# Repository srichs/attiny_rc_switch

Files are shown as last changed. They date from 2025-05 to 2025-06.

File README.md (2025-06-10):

# ATtiny RC Switch

On/Off Switch for RC models driven by PWM signal. Based on ATtiny85, 12V capable. Original project is located [here](https://github.com/DzikuVx/attiny_rc_switch).

This small device allows to turn on/off different devices on RC devices: airplanes, quadcopter drones, cars. 
It uses one RC PWM channel as input and provides power on output pins when channel pulse length is above 1700us.
Excellent to switch LED strips. Output current is up to 500mA.

AVR ATtiny x5 series microcontroller. Compiled code takes slightly above 2kB, so will fit into ATtiny45 and ATtiny85. When smoothing is removed, code will fit into ATtiny25.

To program you can use the [AVR Pocket Programmer](https://www.digikey.com/en/products/detail/sparkfun-electronics/09825/5230949), which costs $20. It is easiest to use a clip to program the microcontroller such as [these](https://www.amazon.com/EC-Buying-Detachable-Programmer-Testing/dp/B0C73GXRR2) or [these](https://www.amazon.com/Programmer-Testing-SOP16-SOIC8-SOIC16/dp/B0CBNG59CB).

## ATtiny RC Switch SMD

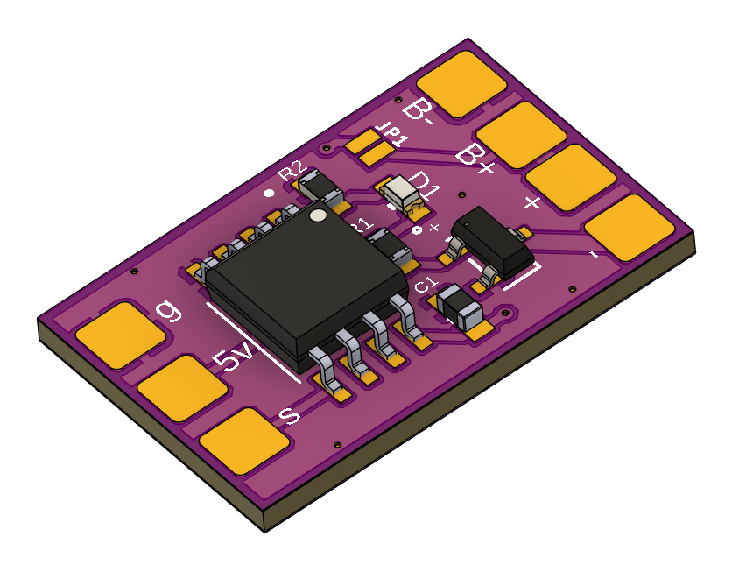
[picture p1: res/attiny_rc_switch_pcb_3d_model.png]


Order the PCB [here](https://oshpark.com/shared_projects/qRILFycT)

## Hardware

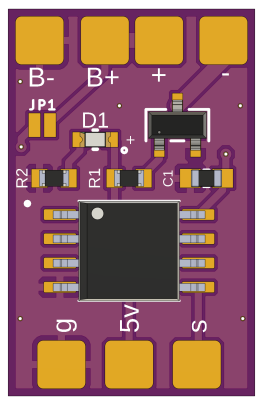
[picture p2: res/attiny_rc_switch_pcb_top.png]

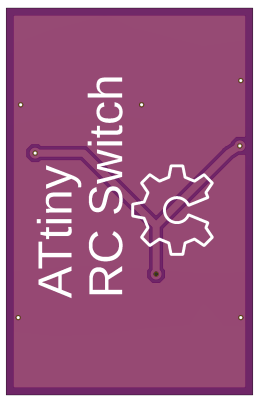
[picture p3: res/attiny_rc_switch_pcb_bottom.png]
PCB Bottom


### BOM

| Label |Part No | Name | Quantity | Subtotal | Link |
|---|---|---|---|---|---|
| U1 | ATTINY85-20SU | ATtiny85 Microcontroller | 1 | $1.50 | [DigiKey](https://www.digikey.com/en/products/detail/microchip-technology/ATTINY85-20SU/735470) |
| U2 | IRLML2502TRPBF | N-Channel MOSFET, 20V, 4.2A SOT-23 | 1 | $0.43 | [DigiKey](https://www.digikey.com/en/products/detail/infineon-technologies/IRLML2502TRPBF/812502) |
| D1 | LTST-C190KRKT | Red LED, SMD 0603, Clear | 1 | $0.14 | [DigiKey](https://www.digikey.com/en/products/detail/liteon/LTST-C190KRKT/386817) |
| R1,R2 | CRGCQ0603F470R | 470 Ohm Resistor, SMD 0603, 1/10W | 2 | $0.20 | [DigiKey](https://www.digikey.com/en/products/detail/te-connectivity-passive-product/CRGCQ0603F470R/8576286) |
| C1 | CC0603KRX7R7BB104 | 0.1uF Capacitor, SMD 0603, 16V | 1 | $0.08 | [DigiKey](https://www.digikey.com/en/products/detail/yageo/CC0603KRX7R7BB104/302822) |
|  | qRILFycT | PCB | 1 | $0.68 | [OSH Park](https://oshpark.com/shared_projects/qRILFycT) |
|  |  |  | Total | $3.03 |  |

### Schematic

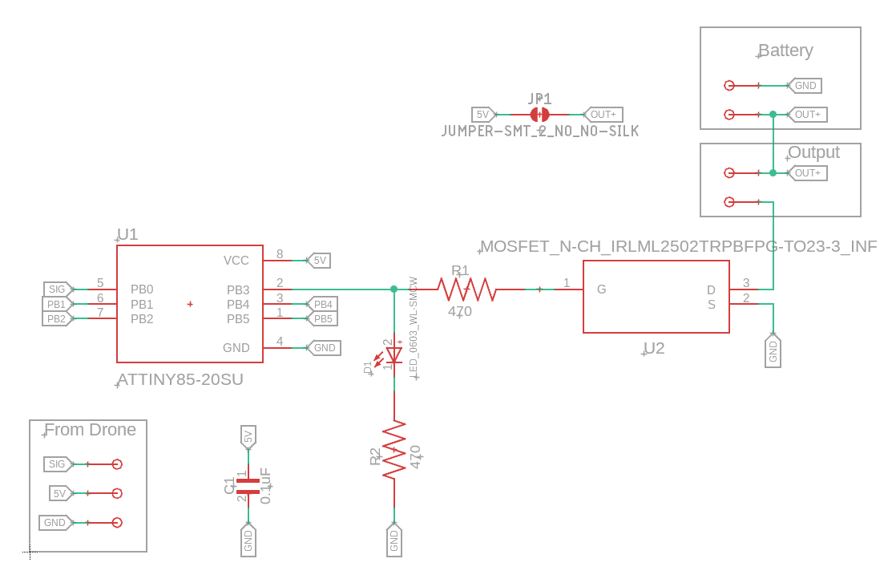
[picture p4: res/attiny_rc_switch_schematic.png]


## ATtiny RC Switch Through Hole

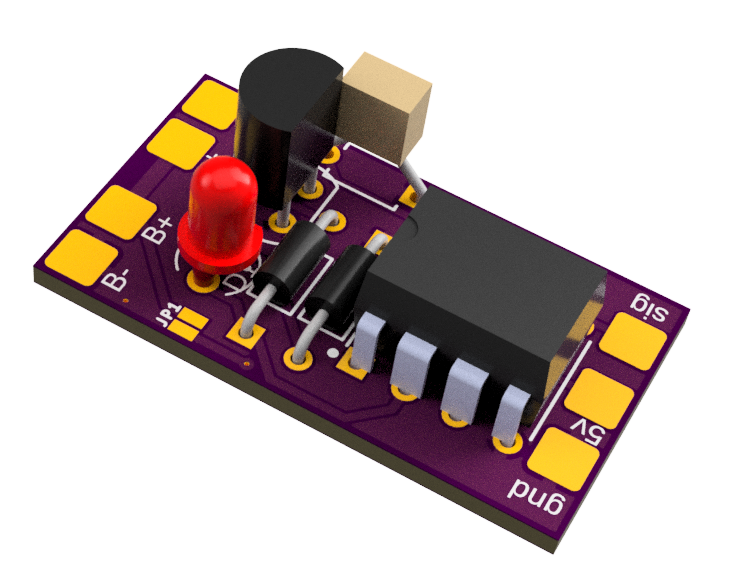
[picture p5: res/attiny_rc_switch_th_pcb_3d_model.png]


Order the PCB [here](https://oshpark.com/)

## Hardware

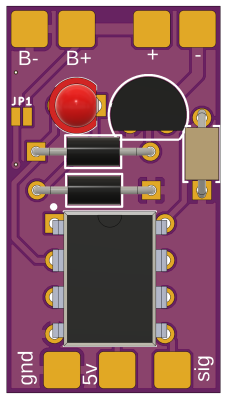
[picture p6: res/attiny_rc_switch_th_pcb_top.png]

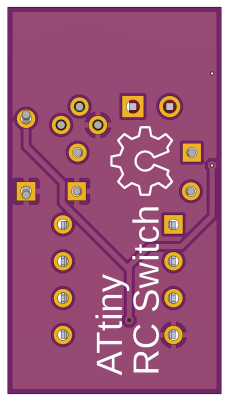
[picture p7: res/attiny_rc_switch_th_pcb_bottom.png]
PCB Bottom


### BOM

| Label |Part No | Name | Quantity | Subtotal | Link |
|---|---|---|---|---|---|
| U1 | ATTINY85-20PU | ATtiny85 Microcontroller | 1 | $1.66 | [DigiKey](https://www.digikey.com/en/products/detail/microchip-technology/ATTINY85-20PU/735469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) |
| U2 | SS8050DTA | NPN BJT, 25V, 1.5A TO92-3 | 1 | $0.37 | [DigiKey](https://www.digikey.com/en/products/detail/onsemi/SS8050DTA/1047325) |
| D1 | 151033RS03000 | Red LED, Round, 3mm, Clear | 1 | $0.16 | [DigiKey](https://www.digikey.com/en/products/detail/w%C3%BCrth-elektronik/151033RS03000/4490003) |
| R1,R2 | CF18JT470R | 470 Ohm Resistor, 1/8W, Axial | 2 | $0.20 | [DigiKey](https://www.digikey.com/en/products/detail/stackpole-electronics-inc/CF18JT470R/1741717) |
| C1 | A104K15X7RF5TAA | 0.1uF Capacitor, 50V, Axial | 1 | $0.26 | [DigiKey](https://www.digikey.com/en/products/detail/vishay-beyschlag-draloric-bc-components/A104K15X7RF5TAA/146011) |
|  |  |  | Total | $2.65 |  |

### Schematic

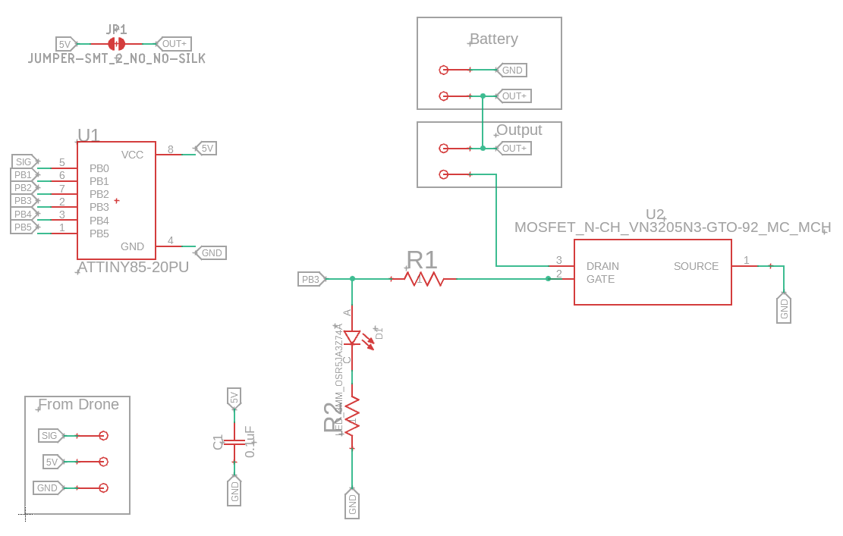
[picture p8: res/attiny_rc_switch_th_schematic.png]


## Notes

* Arduino IDE 1.6.6. Should work on older releases, but never tested

* ATtiny45/85 board definitions. Tested with [damellis/attiny](https://github.com/damellis/attiny)

* Uses 1MHz internal osciallator

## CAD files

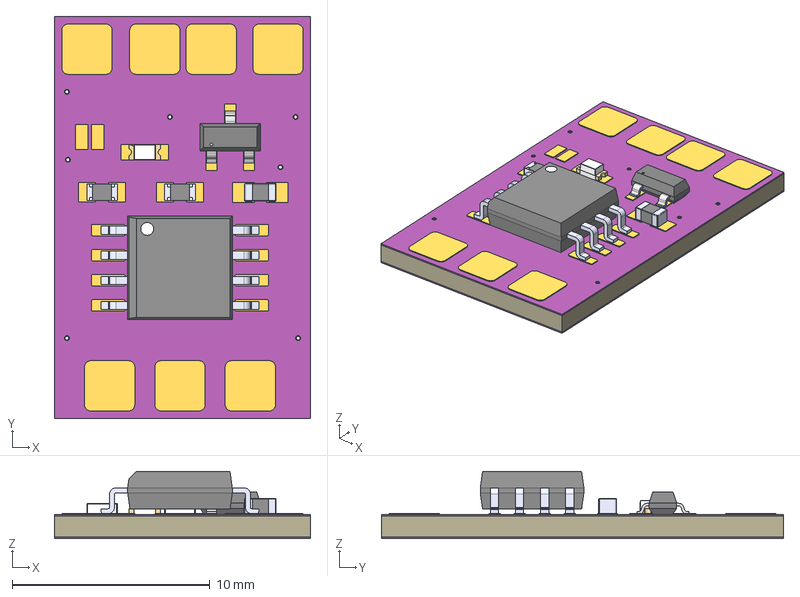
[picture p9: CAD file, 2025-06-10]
pcb/attiny_rc_switch_3d_model.step
13.0 x 20.3 x 3.39 mm
Board
1-copper
16-copper
1-soldermask
16-soldermask
ATTINY85-20SU v1
CC0603ZRY5V9BB104 v1
RCS060310K0JNEA v1 x 2
housing
cover
base x 2
Polarity Mark
IRLML2502TRPBF v1

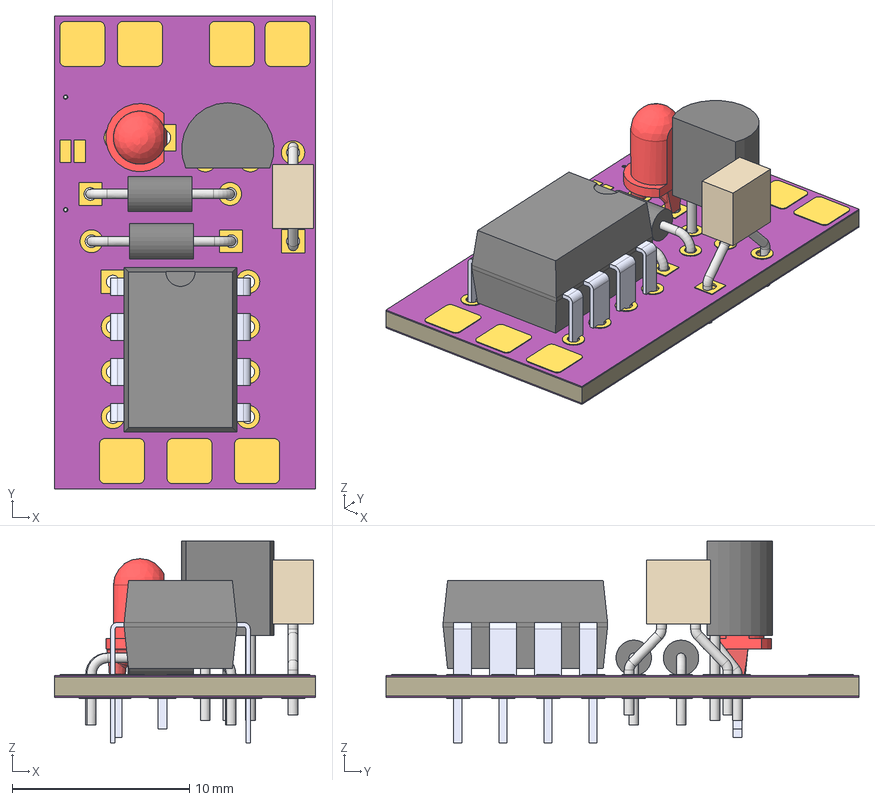
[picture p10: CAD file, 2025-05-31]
pcb/attiny_rc_switch_th_3d_model.step
14.7 x 26.7 x 11.4 mm
Board
ATTINY85-20PU v1
K103K10X7RF5UH5 v1
VN3205N3_G v1
RES_1-8W v1 x 2
OSR5JA3Z74A_OSR5JA3Z74A
SMD_PAD_NO_STENCIL x 7
1-copper
16-copper
1-soldermask
16-soldermask

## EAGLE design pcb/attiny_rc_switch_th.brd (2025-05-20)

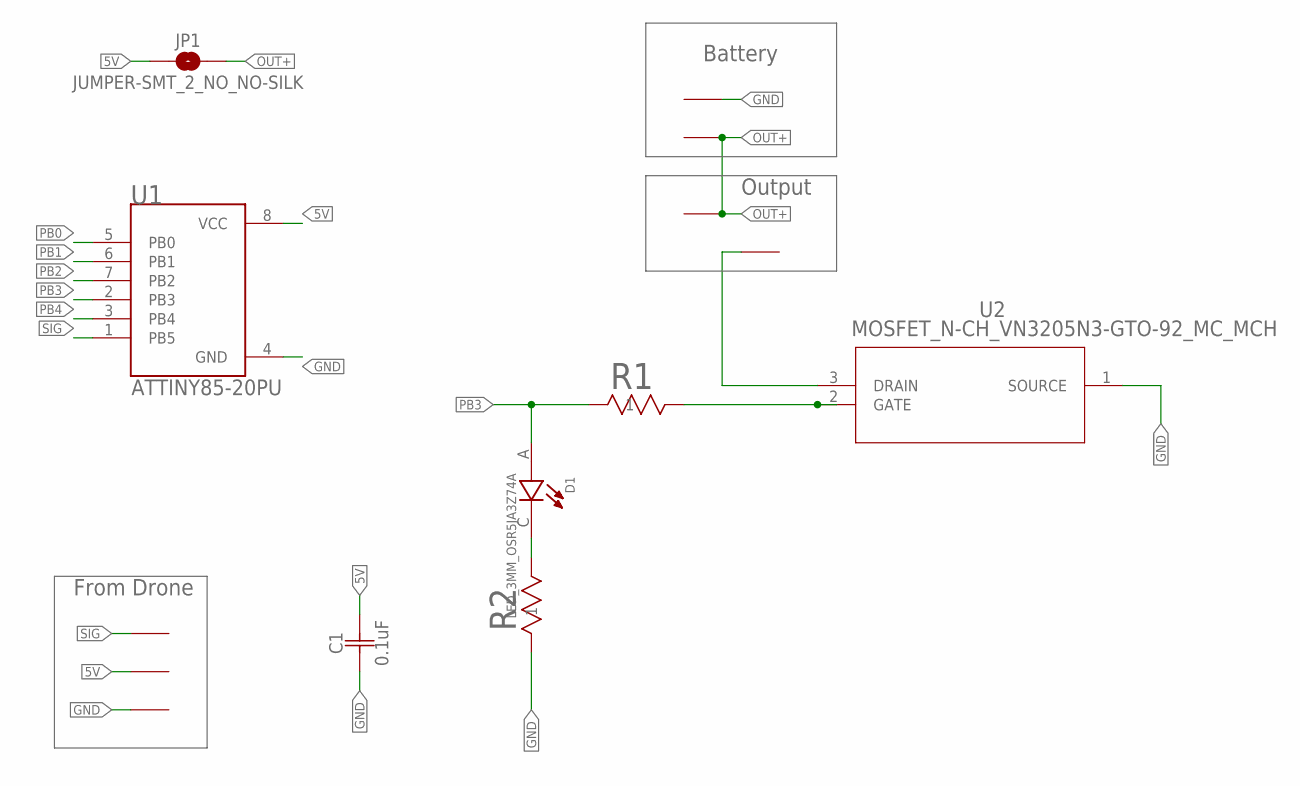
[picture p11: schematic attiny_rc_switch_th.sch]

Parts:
C1: 0.1uF; K10XK10X7RF5UH5
D1: LED_3MM_OSR5JA3Z74A; OSR5JA3Z74A
JP1: JUMPER-SMT_2_NO_NO-SILK; SMT-JUMPER_2_NO_NO-SILK
R1, R2: RESISTOR_1/8W_CF18JTSTA_CF18_STP; RESISTOR_1/8W_CF18JT
U1: ATTINY85-20PU
U2: MOSFET_N-CH_VN3205N3-GTO-92_MC_MCH; MOSFET_N-CH_VN3205N3-G
U$1, U$2, U$3, U$4, U$5, U$6, U$8: SMD_PAD

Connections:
5V: C1.2, JP1.1, U1.8 (VCC), U$1.P$1
GND: C1.1, R2.1, U1.4 (GND), U2.1 (SOURCE), U$2.P$1, U$4.P$1
unnamed: R1.2, U2.2 (GATE)
unnamed: D1.C, R2.2
OUT+: JP1.2, U$3.P$1, U$5.P$1
OUT-: U2.3 (DRAIN), U$6.P$1
PB0: U1.5 (PB0)
PB1: U1.6 (PB1)
PB2: U1.7 (PB2)
PB3: D1.A, R1.1, U1.2 (PB3)
PB4: U1.3 (PB4)
SIG: U1.1 (PB5), U$8.P$1

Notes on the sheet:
From Drone
Battery
Output

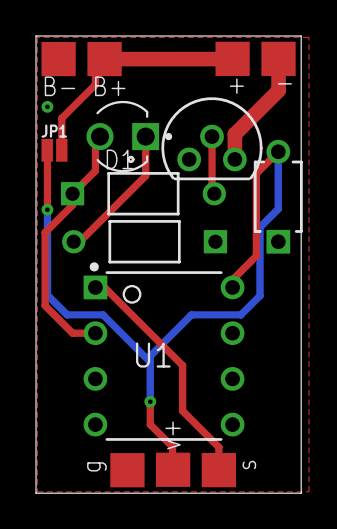
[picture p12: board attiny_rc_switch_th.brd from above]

Board: 2 copper layers, 14.7 x 25.4 mm, 14 parts (0 on the bottom side), 8 nets.

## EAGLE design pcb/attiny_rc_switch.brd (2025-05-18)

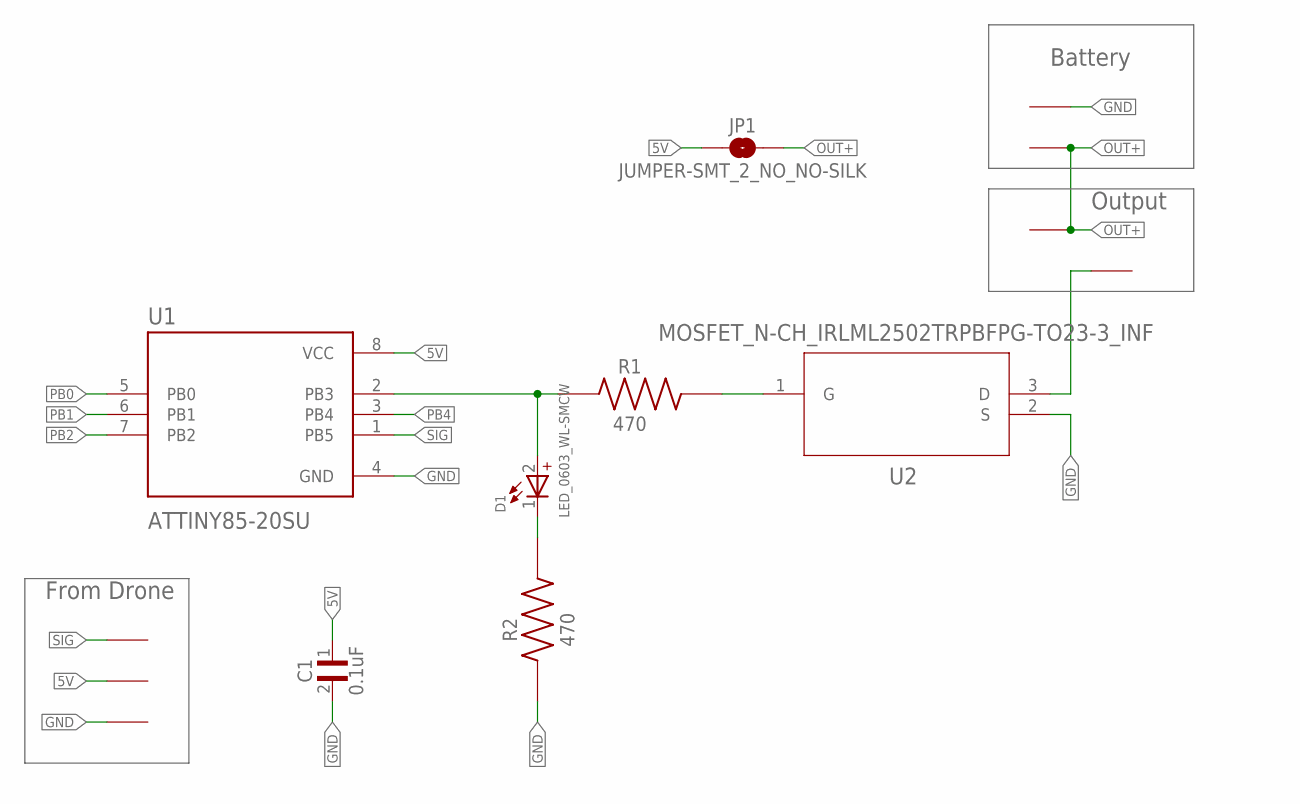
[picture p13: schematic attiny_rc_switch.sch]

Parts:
C1: 0.1uF; CC0603ZRY5V9BB
D1: LED_0603_WL-SMCW
JP1: JUMPER-SMT_2_NO_NO-SILK; SMT-JUMPER_2_NO_NO-SILK
R1, R2: 470; RCS0603
U1: ATTINY85-20SU
U2: MOSFET_N-CH_IRLML2502TRPBFPG-TO23-3_INF; MOSFET_N-CH_IRLML2502TRPBF
U$1, U$2, U$3, U$4, U$5, U$6, U$8: SMD_PAD

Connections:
5V: C1.1, JP1.1, U1.8 (VCC), U$1.P$1
GND: C1.2, R2.1, U1.4 (GND), U2.2 (S), U$2.P$1, U$4.P$1
unnamed: D1.2 (+), R1.1, U1.2 (PB3)
unnamed: R1.2, U2.1 (G)
unnamed: D1.1 (-), R2.2
OUT+: JP1.2, U$3.P$1, U$5.P$1
OUT-: U2.3 (D), U$6.P$1
PB0: U1.5 (PB0)
PB1: U1.6 (PB1)
PB2: U1.7 (PB2)
PB4: U1.3 (PB4)
SIG: U1.1 (PB5), U$8.P$1

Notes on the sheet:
From Drone
Battery
Output

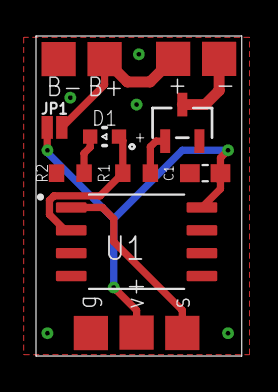
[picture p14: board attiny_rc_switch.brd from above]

Board: 2 copper layers, 11.4 x 17.8 mm, 14 parts (0 on the bottom side), 8 nets.

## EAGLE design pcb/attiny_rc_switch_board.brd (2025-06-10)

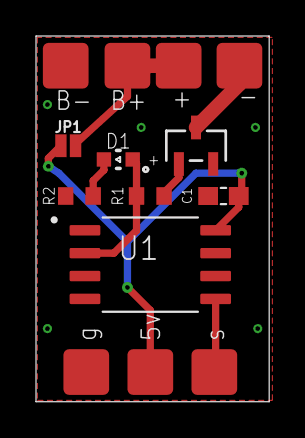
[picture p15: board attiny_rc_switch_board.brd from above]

Board: 2 copper layers, 13.0 x 20.3 mm, 14 parts (0 on the bottom side), 8 nets.

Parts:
C1: 0.1uF; CC0603ZRY5V9BB
D1: LED_0603_WL-SMCW
JP1: JUMPER-SMT_2_NO_NO-SILK; SMT-JUMPER_2_NO_NO-SILK
R1, R2: 470; RCS0603
U1: ATTINY85-20SU
U2: MOSFET_N-CH_IRLML2502TRPBFPG-TO23-3_INF; MOSFET_N-CH_IRLML2502TRPBF
U$1, U$2, U$3, U$4, U$5, U$6, U$7: SMD_PAD_NO_STENCIL

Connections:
5V: C1.1, JP1.1, U1.8, U$2.P$1
GND: C1.2, R2.1, U1.4, U2.2, U$6.P$1, U$7.P$1
unnamed: D1.2, R1.1, U1.2
unnamed: R1.2, U2.1
unnamed: D1.1, R2.2
OUT+: JP1.2, U$4.P$1, U$5.P$1
OUT-: U2.3, U$3.P$1
SIG: U1.5, U$1.P$1

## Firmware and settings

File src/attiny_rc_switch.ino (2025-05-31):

// https://github.com/DzikuVx/attiny_rc_switch
#include <avr/sleep.h>
#include <PinChangeInterrupt.h>

#define SLEEP_MODE_PWR_SAVE (_BV(SM0) | _BV(SM1))
#define adc_disable() (ADCSRA &= ~(1<<ADEN)) // disable ADC (before power-off)
#define adc_enable() (ADCSRA |=  (1<<ADEN)) // re-enable ADC
#define CHANNEL_PIN 0
#define OUTPUT_PIN 3
#define LPF_FACTOR 0.5
#define PULSE_THRESHOLD 1700

volatile unsigned long rising_start = 0;
volatile long channel_length = 0;
volatile long channel_raw = 0;

void enterSleep(void) {
  set_sleep_mode(SLEEP_MODE_PWR_SAVE); // sleep mode is set here
  sleep_enable();
  sleep_mode();                        // System sleeps here
  sleep_disable();
}

/*
 * Start watchdog timer
 * 0=16ms, 1=32ms,2=64ms,3=128ms,4=250ms,5=500ms
 * 6=1 sec,7=2 sec, 8=4 sec, 9= 8sec
 */
void setup_watchdog(int ii) {
  byte bb;
  int ww;
  if (ii > 9 ) ii = 9;
  bb = ii & 7;
  if (ii > 7) bb |= (1 << 5);
  bb |= (1 << WDCE);
  ww = bb;
  MCUSR &= ~(1 << WDRF);
  WDTCR |= (1 << WDCE) | (1 << WDE); // start timed sequence
  WDTCR = bb; // set new watchdog timeout value
  WDTCR |= _BV(WDIE);
}

/*
 * Watchdog interrupt function
 * Actually, we can do absolutely nothing here...
 */
ISR(WDT_vect) {}

void setup() {
  adc_disable();
  pinMode(CHANNEL_PIN, INPUT);
  pinMode(OUTPUT_PIN, OUTPUT);
  digitalWrite(OUTPUT_PIN, HIGH);
  delay(3000);
  digitalWrite(OUTPUT_PIN, LOW);
  attachPinChangeInterrupt(CHANNEL_PIN, onChange, CHANGE);
  setup_watchdog(2); //Set watchdog to wakeup every 128ms to enable/disable output
}

int smooth(int data, float filterVal, float smoothedVal){
  if (filterVal > 1){      // check to make sure param's are within range
    filterVal = .99;
  } else if (filterVal <= 0){
    filterVal = 0;
  }

  smoothedVal = (data * (1 - filterVal)) + (smoothedVal  *  filterVal);
  return (int)smoothedVal;
}

void onChange(void) {
  uint8_t trigger = getPinChangeInterruptTrigger(CHANNEL_PIN);

  if (trigger == RISING) {
    rising_start = micros();
  } else if (trigger == FALLING) {
    channel_raw = micros() - rising_start;
    channel_length = smooth(channel_raw, LPF_FACTOR, channel_length); //Add smoothing to prevent input jitters
  }
}

void loop() {
  if (channel_length > PULSE_THRESHOLD) {
    digitalWrite(OUTPUT_PIN, HIGH);
  } else {
    digitalWrite(OUTPUT_PIN, LOW);
  }
  enterSleep();
}

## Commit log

2016-01-07 electrical improvements
    [attiny_rc_switch.fzz]
2025-05-18 added pcb, changed code & readme
    [attiny_rc_switch.fzz]
2025-05-18 added pcb files
    [attiny_rc_switch.brd, attiny_rc_switch.sch]
2025-05-20 added through hole pcb
    [attiny_rc_switch_th.brd, attiny_rc_switch_th.sch]
2025-05-22 remove unused variable; fix definitions
    [attiny_rc_switch.ino]
2025-05-31 fixed signal pin, changed pads
    [attiny_rc_switch_3d_model.step, attiny_rc_switch_board.brd, attiny_rc_switch_schematic.sch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]
2025-05-31 update pcb order link
2025-05-31 added pcb to BOM
2025-06-10 fixed output pads
    [attiny_rc_switch_3d_model.step, attiny_rc_switch_board.brd]

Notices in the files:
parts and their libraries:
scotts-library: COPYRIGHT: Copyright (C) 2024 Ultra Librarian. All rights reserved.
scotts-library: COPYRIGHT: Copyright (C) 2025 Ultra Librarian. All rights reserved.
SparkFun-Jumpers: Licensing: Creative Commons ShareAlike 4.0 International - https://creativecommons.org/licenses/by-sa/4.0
